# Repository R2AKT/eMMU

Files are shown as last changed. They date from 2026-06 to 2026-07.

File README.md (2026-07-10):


License addendum - https://github.com/R2AKT/eMMU/blob/main/Addendum.txt

# eMMU — Hardware Memory Management Unit for KR580VM80A / Intel 8080

Choose language / Выберите язык:
* [English](#-english)
* [Русский (Russian)](#-русский)

---

# 🇺🇸 English

# eMMU — Hardware Memory Management Unit for Intel 8080 (KR580VM80A)

## 📌 Project Overview
**eMMU (extended Memory Management Unit)** is a high-performance hardware memory management subsystem implemented entirely on discrete TTL logic (74LS, 74ALS series). The project is architected around the vintage **Intel 8080 (KR580VM80A)** 8-bit microprocessor kit and radically overcomes its native architectural limitations.

### Key Features:
* **Memory Expansion:** Increases addressable physical RAM space from **64 KB to 4 MB**.
* **Privilege Isolation:** True hardware-enforced **RING 0 (Kernel Mode)** and **RING 3 (User Mode)** execution environments.
* **Hardware Exceptions:** Immediate generation of a dedicated `/PRIVILEGE_VIOLATION` interrupt upon unauthorized I/O access.
* **Instruction Filtering:** In-flight opcode interception that silently substitutes forbidden user-space interrupt commands (`DI`/`EI`) with safe `NOP` (`0x00`) instructions.
* **Isolated Data Override:** Secure cross-privilege memory window with absolute hardware Write-Protection (WP) blocking of kernel-space RAM during data transfers.
* **Reactive I/O Firewall:** Instant hardware Z-state disabling of the KR580VK38 system controller and premature `~{CS}` peripheral dropping to block rogue I/O cycles.

---

## 🗺️ System Memory Architecture (Memory Map)
The processor's 64 KB logical address space is divided into **4 fixed segments of 16 KB each**. Translation is performed by dynamically swapping logical lines `/AB14` and `/AB15` with physical high-order address lines `/MAB14`...`/MAB21` via **74LS257 (K555KP11)** multiplexers (`DD4`, `DD15`) backed by **74LS670 (K555IR26)** 4x4 register file window memory arrays (`DD7`, `DD16`).

### Logical Segment Map (64 KB) in User Mode (RING 3):
* **`0x0000 – 0x3FFF` [Segment 0]**: **Fully Free User RAM**. Dedicated entirely to user-space application code, stack, or variables. No kernel interrupt vectors or system syscall vectors are reserved here.
* **`0x4000 – 0x7FFF` [Segment 1]**: **Fully Free User RAM**. Available for application execution or heap space.
* **`0x8000 – 0xBFFF` [Segment 2]**: **Fully Free User RAM**. Architecturally designated as the controlled override window for secure Kernel-to-User data exchanges.
* **`0xC000 – 0xFFFF` [Segment 3]**: **Fully Free User RAM**. Allocated for the user-space isolated execution stack and process variables.

### Lower Virtual Space Isolation and Context Switching:
User applications maintain absolute, uninhibited control over the entire 64 KB space—including the lower virtual range (`0x0000–0x0037`)—as the processor never reads instructions from this user-space context during interrupt traps.

The moment a hardware interrupt occurs (`~{INTA} = 0`) or a software trap is triggered, the eMMU forcefully overrides the bus, **switching the memory mapping to the Kernel context (RING 0)**. The true system interrupt vector table is activated on the physical bus exclusively in Kernel mode and strictly starting from address `0x0038` onwards via the `VD1–VD3` diode selector array (`~{LOW_8K} = 0`) and the `DD17` trigger clocked by the `/M1_TRUE` signal.

## 🔌 I/O Control Port Map
MMU configuration and page-table management are handled via a privileged, hardware-isolated I/O port range: **`0x70` – `0x77`** (decoded by **`DD14` / K555ID7 / 74LS138**). Access to these ports is strictly gated by the **`DD12` (K555SP1 / 74LS85)** digital comparator and jumpers `JP1–JP4`. Any unauthorized access attempt from RING 3 instantly locks the decoder and aborts the system cycle.

| Privileged I/O Port | Signal Name | Bus Direction | Functional Description inside the MMU |
| :---: | :--- | :---: | :--- |
| **`0x70`** | `~{PORT_70_SEL}` | Write Only | Writes the physical page index for **Segment 0** into K555IR26 |
| **`0x71`** | `~{PORT_71_SEL}` | Write Only | Writes the physical page index for **Segment 1** into K555IR26 |
| **`0x72`** | `~{PORT_72_SEL}` | Write Only | Writes the physical page index for **Segment 2** into K555IR26 |
| **`0x73`** | `~{PORT_73_SEL}` | Write Only | Writes the physical page index for **Segment 3** into K555IR26 |
| **`0x74`** | `~{PORT_74_SEL}` | — | Reserved internal auxiliary control line |
| **`0x75`** | `~{PORT_75_SEL}` | Write Only | **Shadow ROM Override:** Flips trigger `DD3` to permanently disable Boot ROM after BIOS is cached to Kernel RAM |
| **`0x76`** | `~{PORT_76_SEL}` | Write Only | **KERNEL_OVERRIDE Control:** Toggles trigger `DD19` to engage/disengage user-space window mapping |
| **`0x77`** | `~{PORT_77_SEL}` | — | Reserved system port for future hardware extensions |

---

## 🛠️ Hardware-Enforced Protection Mechanisms

### 1. Boot Logic, Shadow ROM, and Diode Selection (`VD1–VD3`)
At power-on or system reset (`~{RESOUT} = 0`), the `DD3` trigger defaults to `~{ROM_EN} = 0`, forcing raw physical memory translation off. The **`VD1–VD3`** diode array strictly monitors logical address ranges, asserting **`~{LOW_8K} = 0`**. 

Gated together with `~{ROM_CS}`, this activates the `DD35` Shadow Boot ROM **strictly within the logical bounds of `0x0000–0x1FFF`**, completely preventing phantom mirroring across higher address blocks. The primary bootloader copies the core BIOS/OS image into fast physical system RAM, then fires an `OUT 0x75` command. The resulting `~{PORT_75_SEL}` strobe flips the `DD3` trigger—permanently disabling the Shadow ROM and the diode array until the next cold reset, instantly reclaiming Segment 0 for user space.

### 2. Privileged I/O Gating and the Reactive I/O Firewall
The board incorporates a reactive hardware monitoring matrix over the I/O subsystem. In RING 3, discrete gates `DD11` and `DD44` actively watch the execution of system input/output command strobes **`~{IOR}`** and **`~{IOW}`**.
* **Violation Detection:** Any rogue `IN`/`OUT` execution from user space targeted at protected peripheral spaces triggers an immediate **`~{IO_VIOLATION} = 0`** fault signal. Trigger **`DD55`** latches this hardware exception and relays a persistent **`/PRIVILEGE_VIOLATION`** interrupt request to the system controller via the `JP5–JP12` matrix. The kernel clears the exception state by pulsing port `0x76`.
* **Hardware Interception Matrix:** Simultaneously with the interrupt, the asserted `~{IO_VIOLATION} = 0` line instantly forces the main **KR580VK38** system controller data bus transceivers into a high-impedance Z-state, effectively disconnecting the CPU's local lines. Mitigation is achieved by **prematurely forcing Chip Select (`~{CS}`) lines to high (`1`)** on the external peripheral decoders. This hardware drop completely isolates external LSI chips (such as KR580VV55 or KR580VI53) *before* the active logical `~{IOW}` or `~{IOR}` bus signals finish their machine cycle, making the theft or corruption of internal peripheral control data physically impossible.

### 3. Opcode Invalidation (`DI` / `EI` Gating)
During RING 3 execution, the `DD26` decoder tracks the exact appearance of `0xF3` (`DI`) and `0xFB` (`EI`) opcodes strictly inside `M1` fetch cycles. Upon matches, the `~{DI-EI_CODE}` line falls low, opening the `DD13` bus-override buffer which grounds the processor's data lines on-the-fly. The processor registers a safe **`NOP` (`0x00`)** instruction instead, leaving user-space interrupts enabled and maintaining total OS multitasking stability.

### 4. Delayed Privilege Escalation and Symmetric Returns
When an interrupt hits (`~{INTA} = 0`), the CPU executes the initial branch cycle completely in RING 3. The return address (`PC`) is written to the user stack using user-space translation tables. Because privilege escalation to RING 0 (`/KERNEL_MODE = 1`) is strictly delayed until the first opcode fetch (`M1`) from vector `0x0038` (handled by the `/M1_TRUE` trigger), the kernel's physical pages are fundamentally insulated from being overwritten by a corrupt user-space `SP`.

Symmetric returns are cleanly automated via the `~{RET_STROBE}` line, which intercepts the `RET` (`0xC9`) instruction in its `M1` cycle. The processor reads its return coordinates from the stack *after* the hardware has already swapped the context back to RING 3, ensuring the kernel's execution context is kept clean.

### 5. Secure Context Override (`KERNEL_OVERRIDE`)
To transfer blocks between Kernel Mode and User Mode safely, the kernel writes to port `0x76`, setting `~{KERNEL_OVERRIDE} = 0`. Inside Segment 2 (`0x8000–0xBFFF`), a **K555LI1 (74LS08)** logical `AND` gate forces the IR26 registers and KP11 multiplexers into translation mode. While Segments 0, 1, and 3 continue to map true kernel pages (mirrored by the OS inside register positions 0, 1, and 3 of the IR26 files), Segment 2 securely routes data directly to the physical user process page.

Crucially, the active-low `~{KERNEL_OVERRIDE_EN} = 0` line is fed directly into the active-low enable input `E1` (pin 4) of the **`DD39`** kernel memory decoder. The moment an override cycle runs, **`DD39` is forcefully disabled by the hardware**, driving `~{CS_32}` and `~{CS_64}` high. Physical kernel RAM chips (`DD50`, `DD51`) are completely decoupled from the data bus, making malicious memory corruption through illegal user pointers mathematically impossible.

---

# 🇷🇺 Русский

## 📌 Описание проекта
**eMMU (extended Memory Management Unit)** — это высокоуровневый аппаратный диспетчер памяти, реализованный на жесткой ТТЛ-логике (серии К555/К1533). Проект спроектирован вокруг классического микропроцессорного комплекта **КР580ВМ80А (Intel 8080)** и полностью решает его базовые архитектурные ограничения.

### Ключевые возможности:
* **Расширение памяти:** Адресация физического ОЗУ увеличивается с **64 КБ до 4 МБ**.
* **Разделение привилегий:** Полноценная аппаратная реализация режимов **RING 0 (Ядро)** и **RING 3 (Пользователь)**.
* **Аппаратные исключения:** Генерация прерывания `/PRIVILEGE_VIOLATION` при несанкционированном доступе к портам ввода-вывода.
* **Фильтрация команд:** Перехват и «тихая» подмена запрещенных инструкций `DI`/`EI` в пространстве пользователя на безопасные `NOP` (`0x00`).
* **Защищенный оверрайд:** Межпривилегированный сегмент обмена данными с жесткой WP-блокировкой системного ОЗУ.
* **Аппаратный I/O Firewall:** Принудительное Z-глушение ВК38 и опережающее отключение сигналов `~{CS}` периферии при нелегальном доступе к портам в RING 3.

---

## 🗺️ Архитектурная карта памяти (Memory Map)
Логическое адресное пространство процессора (64 КБ) разделено на **4 фиксированных сегмента объемом по 16 КБ каждое**. Трансляция осуществляется заменой логических линий `/AB14` и `/AB15` на физические `/MAB14`...`/MAB21` через мультиплексоторы **К555КП11 (`DD4`, `DD15`)** и регистровую память окон **К555ИР26 (`DD7`, `DD16`)**.

### Сетка логических сегментов процессора (64 КБ) в режиме Пользователя (RING 3):
* **`0x0000 – 0x3FFF` [Сегмент 0]**: **Полностью свободен**. Назначение определяется пользователем (код / стек / данные).
* **`0x4000 – 0x7FFF` [Сегмент 1]**: **Полностью свободен**. Назначение определяется пользователем (код / стек / данные).
* **`0x8000 – 0xBFFF` [Сегмент 2]**: **Полностью свободен**. Назначение определяется пользователем. Аппаратно выделен как область контролируемого оверрайда для доступа Ядра к пользовательской памяти.
* **`0xC000 – 0xFFFF` [Сегмент 3]**: **Полностью свободен**. Назначение определяется пользователем (код / стек / данные).

### Механизм изоляции и принудительного переключения:
Все четыре сегмента в пользовательском режиме полностью очищены от обязательного присутствия системных структур ядра. Пользовательское ПО может монопольно распоряжаться всем пространством 64 КБ.

В момент программного вызова (команды `RST`, `CALL`) или аппаратного прерывания (`~{INTA} = 0`), eMMU аппаратно перехватывает шину и **принудительно переключает адресное пространство в контекст Ядра (RING 0)**. Истинная системная база ОС активируется на физической шине строго в режиме ядра, защищая пользовательские данные.

---

## 🔌 Карта портов ввода-вывода (I/O Control Map)
Управление диспетчером памяти выполняется через диапазон портов **`0x70` – `0x77`** (дешифратор **`DD14` / К555ИД7**). Доступ аппаратно защищен компаратором **`DD12` (К555СП1)** и блоком джамперов `JP1–JP4`. Обращение из RING 3 мгновенно блокирует дешифратор и вызывает сбой системы.

| Порт I/O | Название сигнала | Направление | Функциональное назначение в MMU |
| :---: | :--- | :---: | :--- |
| **`0x70`** | `~{PORT_70_SEL}` | Запись | Физический адрес страницы для **Сегмента 0** в К555ИР26 |
| **`0x71`** | `~{PORT_71_SEL}` | Запись | Физический адрес страницы для **Сегмента 1** в К555ИР26 |
| **`0x72`** | `~{PORT_72_SEL}` | Запись | Физический адрес страницы для **Сегмента 2** в К555ИР26 |
| **`0x73`** | `~{PORT_73_SEL}` | Запись | Физический адрес страницы для **Сегмента 3** в К555ИР26 |
| **`0x74`** | `~{PORT_74_SEL}` | — | Резервный управляющий канал периферии |
| **`0x75`** | `~{PORT_75_SEL}` | Запись | **Отключение теневого ПЗУ**: защелка триггера `DD3` после копирования BIOS в ОЗУ ядра |
| **`0x76`** | `~{PORT_76_SEL}` | Запись | **Включение / выключение режима KERNEL_OVERRIDE** (управление триггером `DD19`) |
| **`0x77`** | `~{PORT_77_SEL}` | — | Резервный системный порт диспетчера |

---

## 🛠️ Механизмы аппаратной защиты

### 1. Логика старта, теневое ПЗУ и диодный селектор `VD1–VD3`
При подаче питания или системном сбросе (`~{RESOUT} = 0`) триггер `DD3` автоматически выставляет `~{ROM_EN} = 0`. Трансляция отключена. Диодная сборка **`VD1–VD3`** непрерывно идентифицирует обращения процессора к нижним адресам памяти и формирует сигнал **`~{LOW_8K} = 0`**. 

В связке с цепью `~{ROM_CS}` это аппаратно активирует теневое ПЗУ `DD35` **строго в границах диапазона `0x0000–0x1FFF`**, исключая его ложное зеркалирование на остальную память. Первичный бутлоадер переносит код BIOS/ОС в физическое системное ОЗУ, после чего выполняет команду `OUT 0x75`. Сигнал `~{PORT_75_SEL}` сбрасывает триггер `DD3` — теневое ПЗУ и диодная сборка навсегда отключаются до следующего аппаратного RESET, освобождая Сегмент 0 для полноценного использования пользователем.

### 2. Защита ввода-вывода и Экспериментальный I/O Firewall
Плата реализует жесткий аппаратный контроль пространства ввода-вывода. В режиме RING 3 элементы логики `DD11` и `DD44` непрерывно мониторят появление системных стробов чтения/записи портов **`~{IOR}`** и **`~{IOW}`**.
* **Детектирование нарушений:** Любая попытка вызова команд `IN`/`OUT` в пользовательском пространстве к служебным/управляющим портам eMMU формирует сигнал **`~{IO_VIOLATION} = 0`**. Триггер **`DD55`** мгновенно фиксирует (защелкивает) это событие и через систему джамперов `JP5–JP12` отправляет сигнал прерывания **`/PRIVILEGE_VIOLATION`** контроллеру прерываний для обработки операционной системой. Сброс триггера нарушения производится ядром через порт `0x76`.
* **ЭКСПЕРИМЕНТАЛЬНАЯ защита (Блокировка периферии):** Сигнал нарушения `~{IO_VIOLATION} = 0` мгновенно переводит системный контроллер **КР580ВК38** в высокоимпедансное Z-состояние, изолируя локальные линии данных процессора. Предотвращение несанкционированного выполнения операции (чтения служебных/управляющих данных или записи деструктивного мусора в регистры) достигается за счет **опережающего аппаратного снятия сигналов выбора кристалла `~{CS}`** с дешифраторов внешних периферийных модулей (они принудительно уводятся в `1`). Блокировка срабатывания логики внешних БИС происходит до того, как текущие системные стробы `~{IOW}` или `~{IOR}` успеют завершить машинный цикл и подняться обратно в пассивное состояние, гарантируя полную изоляцию служебных портов.

### 3. Блокировка `DI` / `EI`
В пользовательском режиме компаратор `DD26` отслеживает опкоды `0xF3` (`DI`) и `0xFB` (`EI`) в цикле `M1`. При совпадении активируется линия `~{DI-EI_CODE}`, открывая буфер глушения шины `DD13`, который прижимает данные процессора к нулю. Процессор выполняет операцию **`NOP` (`0x00`)**.

### 4. Межпривилегированные переходы и Стек
При прерывании или системном вызове (`~{INTA} = 0`) процессор выполняет переход полностью в контексте RING 3. Адрес возврата (`PC`) сохраняется в текущем пользовательском стеке по правилам трансляции страниц пользователя. Поскольку переключение в RING 0 (`/KERNEL_MODE = 1`) происходит отложено — строго по сигналу `/M1_TRUE` при выборке первой инструкции обработчика ядра из предела `0x0038`, физические адреса ядра гарантированно защищены от записи со стороны пользовательского указателя стека `SP`.

Автоматический выход в RING 3 осуществляется по сигналу `~{RET_STROBE}` при детекции опкода `RET` (`0xC9`) в цикле `M1`. Чтение стека процессором происходит уже в контексте пользовательских таблиц страниц.

### 5. Синхронизация KERNEL_OVERRIDE
Включение режима контролируемого доступа к памяти пользователя производится командой `OUT 0x76`, взводящей линию `~{KERNEL_OVERRIDE} = 0`. В режиме оверрайда, привязанном строго к Сегменту 2 (`0x8000–0xBFFF`), логическое «И» на микросхеме **К555ЛИ1** принудительно включает ИР26 и КП11. Для Сегментов 0, 1 и 3 на шину транслируются системные адреса ядра (продублированные ОС в ячейках 0, 1 и 3 ИР26), а для Сегмента 2 — страница пользователя.

Строб `~{KERNEL_OVERRIDE_EN} = 0` заведен на инверсный вход разрешения `E1` дешифратора памяти ядра **`DD39`**. В момент работы оверрайда дешифратор `DD39` **аппаратно блокируется**, уводя сигналы `~{CS_32}` и `~{CS_64}` в пассивную единицу, что полностью исключает риск затирания памяти ядра пользовательскими данными. По окончании работы ядро сбрасывает режим оверрайда повторной записью в порт `0x76`.

---
*Engineered as part of the eMMU Protected System Architecture.*

---

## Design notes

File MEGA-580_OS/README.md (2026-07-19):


License addendum - https://github.com/R2AKT/eMMU/blob/main/Addendum.txt

# 🖥️ MEGA-580 OS

**Монолитная операционная система реального времени для архитектуры КР580ВМ80А (i8080-совместимая)**







---

## 📖 О проекте

**MEGA-580 OS** — экспериментальная монолитная операционная система, написанная полностью на ассемблере КР580ВМ80А (~3500 строк кода). ОС разработана для работы на советской микроэлектронике серии КР580 и поддерживает современные POSIX-подобные концепции: вытесняющую многозадачность, виртуальную файловую систему, символьные устройства, сигналы и аппаратную защиту памяти.

Ключевая архитектурная особенность — использование собственной сегментно-страничной системы памяти **eMMU rev_2.0** с четырьмя сегментами по 16 КБ и режимом `KERNEL_OVERRIDE` для безопасного доступа ядра (Ring 0) к пользовательской памяти (Ring 3).

---

## ⚠️ Важное примечание о статусе проекта

> **Подсистема системных вызовов (`SYSCALL_TABLE`) находится в стадии активной переработки.**  
> В текущей сборке таблица `SYSCALL_TABLE` содержит только заглушку `syscall_bad_number`. Реализация полного набора POSIX-сисколлов (`sys_exit`, `sys_open`, `sys_read`, `sys_write`, `sys_gettimeofday` и др.) запланирована в ближайших коммитах.
>
> **Вся остальная инфраструктура ядра** (VFS, RTC, NVRAM, TTY, LPT, планировщик, обработчик прерываний) **полностью функциональна, протестирована и готова к интеграции**.

---

## ✨ Ключевые особенности

### 🏗️ Архитектура ядра
- **Монолитное ядро** с вытесняющей многозадачностью
- **Двухуровневая защита памяти** (Ring 0 / Ring 3) через eMMU rev_2.0
- **Режим KERNEL_OVERRIDE** для атомарного доступа ядра к памяти Ring 3
- **Динамические приоритеты** с aging и насыщением до 255
- **POSIX-подобные сигналы** (16 сигналов, маски SIG_FATAL)
- **SMC-патчинг** (Self-Modifying Code) для адресации портов ISR

### 📁 Виртуальная файловая система (VFS)
- **Таблица коммутации драйверов** `VFS_SWITCH_TABLE` (32 Major × 10 байт)
- **Таблица монтирования устройств** `DEV_MOUNT_TABLE` (16 слотов × 6 байт)
- **Таблица Inode** `VFS_INODE_TABLE` (64 Inode × 16 байт)
- **Глобальная таблица файлов** `SYS_FILE_TABLE` (128 дескрипторов × 10 байт)
- **Локальная таблица FD** в PCB (16 дескрипторов на процесс)
- **Оптимизация хвостового вызова** через трюк `XTHL` в `k_vfs_dispatch`

### 🕐 Подсистема RTC/NVRAM
- **Аппаратные часы реального времени** на базе КР512ВИ1 (аналог DS12885)
- **Двусторонний конвертер эпохи**: `k_rtc_convert_raw_to_unix` ↔ `k_rtc_convert_unix_to_raw`
- **32-битный UNIX Time** (Little-Endian) с диапазоном 01.01.2026 — 07.02.2106
- **Защита от бита UIP**: атомарное чтение в окно 244 мкс
- **NVRAM 50 байт** (адреса 0x0E — 0x3F) с блочными операциями
- **Обработка високосных лет** через таблицу `k_rtc_days_before_month`

### 🖥️ Подсистема TTY
- **До 4-х независимых консолей** (TTY0 — TTY3)
- **Приоритетный автодетект**: КР580ВВ51А + КР580ВИ53, затем NS16550
- **Кольцевые буферы** RX/TX по 64 байта
- **POSIX termios-флаги**: ECHO, ICANON, ISIG, ICRNL, OPOST
- **Управляющие символы**: Ctrl+C, Ctrl+D, Ctrl+U, Backspace, Ctrl+Q/S

### 🖨️ Подсистема LPT
- **До 2-х параллельных портов** (LPT0, LPT1)
- **Приоритетный автодетект**: Intel 82C11, затем КР580ВВ55А
- **FIFO-буфер отложенной записи** 48 байт
- **Асинхронный Handshake Centronics** через BSR-команды РРУ
- **32-битный счётчик** выведенных байт `O_LP_BYTES_WRITTEN`

---

## 🖥️ Поддерживаемое оборудование

### Микропроцессоры
- **КР580ВМ80А** (i8080-совместимый, 2.5 МГц)

### Контроллеры прерываний
- **КР580ВН59** (аналог Intel 8259A) — Master

### Системные таймеры
- **КР580ВИ53** (аналог Intel 8253) — квант 20 мс (50 Гц)

### Часы реального времени
- **КР512ВИ1** (аналог DS12885) — RTC + 50 байт NVRAM

### Последовательные интерфейсы
- **КР580ВВ51А** (аналог Intel 8251A) — USART
- **NS16550 / 16550A** — UART с FIFO

### Параллельные интерфейсы
- **КР580ВВ55А** (аналог Intel 8255A) — PPI
- **Intel 82C11** — специализированный LPT-контроллер

### Контроллеры памяти
- **К555ИР26** — сегментно-страничный модуль eMMU rev_2.0

---

## 📂 Структура проекта

```
MEGA-580_OS/
├── kernel.lst                    # Монолитный листинг ядра (основной файл)
├── kernel.mem                    # Распределение памяти Ring 0
│
├── include/                      # Заголовочные файлы
│   ├── kernel.inc                # Основные константы ядра
│   ├── kernel_time.inc           # Константы таймера
│   ├── kernel_time.mem           # SYS_TICK_COUNTER, SYS_UNIX_TIME
│   ├── hw.inc                    # Порты периферии
│   ├── pcb.inc / pcb.mem         # Структура PCB (64 байта)
│   ├── vfs.inc / vfs.mem         # VFS-константы и таблицы
│   ├── chrdev.inc / chrdev.mem   # Символьные устройства
│   ├── syscall.inc / syscall.mem # Таблица сисколлов
│   ├── tty.inc / tty.mem         # TTY-структуры (160 байт)
│   ├── lp.inc / lp.mem           # LPT-структуры (80 байт)
│   ├── signals.inc               # POSIX-сигналы (16 бит)
│   ├── devices.inc               # Major/Minor номера
│   ├── hw_i8251.inc / mem        # КР580ВВ51А
│   ├── hw_ns16550.inc / mem      # NS16550
│   ├── hw_rtc.inc / mem          # КР512ВИ1
│   ├── rtc.inc / rtc.mem         # RTC подсистема
│   ├── rtc_core.inc              # RTC VFS-мосты
│   ├── rtc_epoch.inc / mem       # Epoch-конвертер
│   ├── rtc_nvram.inc / mem       # NVRAM операции
│   └── panic.inc                 # Коды паники ядра
│
└── kernel/                       # Модули ядра
    ├── vfs.asm                   # VFS-диспетчеры
    ├── pcb.asm                   # Планировщик
    ├── syscall.asm               # Шлюз сисколлов
    ├── chrdev.asm                # Коммутатор символьных устройств
    ├── tty_core.asm              # TTY-драйвер
    ├── lp_core.asm               # LPT-драйвер
    ├── hw.asm                    # Инициализация периферии
    ├── hw_i8251.asm              # HAL КР580ВВ51А
    ├── hw_ns16550.asm            # HAL NS16550
    ├── hw_lp8255.asm             # HAL КР580ВВ55А
    ├── hw_lp82c11.asm            # HAL Intel 82C11
    ├── hw_rtc.asm                # HAL КР512ВИ1
    ├── rtc.asm                   # RTC-драйвер
    ├── rtc_core.asm              # VFS-мосты RTC/NVRAM
    ├── rtc_epoch.asm             # Epoch-конвертер
    ├── rtc_nvram.asm             # NVRAM-операции
    ├── panic.asm                 # Обработчик паники
    └── sys_write.asm             # Сисколл записи
```

---

## 📊 Технические метрики

| Параметр | Значение |
|---|---|
| Объём кода | ~3500 строк ассемблера |
| Размер ядра | 8 КБ (тень ПЗУ) |
| Максимум процессов | 32 (`PCB_TABLE` = 2 КБ) |
| Размер PCB | 64 байта |
| Квант планировщика | 20 мс (50 Гц) |
| Максимум TTY | 4 консоли |
| Максимум LPT | 2 порта |
| Размер TTY-слота | 160 байт |
| Размер LPT-слота | 80 байт |
| Размер файла VFS | 10 байт |
| Максимум файлов в системе | 128 |
| Максимум файлов на процесс | 16 |
| Объём NVRAM | 50 байт |
| Размер сегмента eMMU | 16 КБ |
| Количество сегментов | 4 |
| Поддержка високосных лет | ✅ (до 2099) |
| Диапазон UNIX_TIME | 01.01.2026 — 07.02.2106 |

---

## 🚀 Последовательность холодного старта

```
┌─────────────────────────────────────────────────────────────┐
│ 1. Теневое ПЗУ (0x0000)                                     │
│    └─ boot_start → cold_boot                                │
├─────────────────────────────────────────────────────────────┤
│ 2. Перенос ядра в верхнее ОЗУ (EMMU_PAGE_2 = 0x8000)       │
│    └─ LXI H, upper_ram_stage2+EMMU_PAGE_2 → PCHL            │
├─────────────────────────────────────────────────────────────┤
│ 3. Отключение ПЗУ через порт 0x75                           │
│    └─ OUT EMMU_ROM_DISABLE                                  │
├─────────────────────────────────────────────────────────────┤
│ 4. Зеркальный перенос ядра в нижнее ОЗУ (0x0000)           │
│    └─ EMMU_PAGE_2 → EMMU_PAGE_0                             │
├─────────────────────────────────────────────────────────────┤
│ 5. Чистый старт из нижнего ОЗУ                              │
│    └─ kernel_clean_start                                    │
├─────────────────────────────────────────────────────────────┤
│ 6. Инициализация подсистем (Этапы 5.1 — 5.11)              │
│    ├─ 5.1  k_pcb_subsys_init                                │
│    ├─ 5.2  k_tty_subsys_init                                │
│    ├─ 5.3  k_lp_subsys_init                                 │
│    ├─ 5.4  k_vfs_subsys_init + регистрация драйверов       │
│    ├─ 5.5  hw_sys_init (ВИ53)                               │
│    ├─ 5.6  k_rtc_boot_sync_unix_time                        │
│    ├─ 5.7  k_tty_carousel_auto_build                        │
│    ├─ 5.8  vfs_mount_tty_nodes                              │
│    ├─ 5.9  k_lp_carousel_auto_build                         │
│    ├─ 5.10 vfs_mount_lp_nodes                               │
│    └─ 5.11 hw_int_init (ВН59)                               │
├─────────────────────────────────────────────────────────────┤
│ 7. Разрешение прерываний                                    │
│    └─ EOI → EI → idle_loop (HLT)                            │
└─────────────────────────────────────────────────────────────┘
```

---

## 🏛️ Архитектура VFS

### Двухуровневая система диспетчеризации

```
Ring 3: write(fd, buf, len)
    │
    ▼
sys_call_entry (RST 6)
    │
    ▼
sys_write
    │
    ▼
k_vfs_get_file_struct_address(fd) → HL = адрес Inode
    │
    ▼
vfs_chrdev_write(Major, Minor, buf, len)
    │
    ▼
SYS_CHRDEV_SWITCH[Major].write_ptr → PCHL
    │
    ▼
tty_write_bridge / lp_write_bridge / rtc_write_bridge
    │
    ▼
Физический драйвер (hw_i8251_put_char / hw_82c11_put_char)
    │
    ▼
Кремний (КР580ВВ51А / Intel 82C11 / КР512ВИ1)
```

### Major-номера устройств

| Major | Устройство | Описание |
|---|---|---|
| 1 | `/dev/null` | Системный поглотитель данных |
| 2 | `/dev/zero` | Системный генератор нулей |
| 3 | `/dev/mem` | Прямой физический доступ к ОЗУ ядра |
| 4 | `/dev/tty*` | Последовательные консоли (ВВ51/16550) |
| 5 | `/dev/pty*` | Псевдо-терминалы для сетевых сессий |
| 6 | `/dev/lp*` | Параллельный порт принтера (82C11/ВВ55А) |
| 8 | `/dev/rtc` | Аппаратные часы реального времени |
| 9 | `/dev/nvram` | Энергонезависимая память 50 байт |

---

## 🕐 Подсистема RTC/NVRAM

### Полный двусторонний стек конвертации

```
k_rtc_raw_sec..year  ←→  k_rtc_convert_raw_to_unix  ←→  SYS_UNIX_TIME (32 bit)
                            k_rtc_convert_unix_to_raw
```

### Ключевые особенности

- **Защита от бита UIP**: Чтение регистров только в безопасное окно 244 мкс
- **Тест через Регистр B**: Исключение ложных срабатываний от динамического бита UIP
- **Оптимизированная арифметика**: Умножение дней на 86400 через разложение `65536 + 20864`
- **Таблица `k_rtc_days_before_month`** в формате `.dw` (16 бит) для поддержки октября/ноября/декабря
- **Корректная обработка високосных лет**: `(год % 4 == 0) && (месяц > 2)`

### VFS-мосты

| Устройство | Major | Minor | Функции |
|---|---|---|---|
| `/dev/rtc` | 8 | 1 | `rtc_read_bridge`, `rtc_write_bridge` |
| `/dev/nvram` | 9 | 0 | `nvram_read_bridge`, `nvram_write_bridge` |

Все мосты используют атомарное управление `KERNEL_OVERRIDE` через порт `0x76` для безопасного доступа к памяти Ring 3.

---

## 🔄 Планировщик задач

### Динамические приоритеты с aging

```
Формула приоритета: DYNAMIC = STATIC + NICE + CPU_TICKS
Насыщение: min(255, DYNAMIC)
```

- **Штрафной счётчик**: `O_CPU_TICKS` увеличивается при каждом кванте выполнения
- **Aging**: `O_CPU_TICKS--` для всех процессов, кроме `ST_ZOMBIE`
- **Выбор кандидата**: Линейный скан 32 слотов `PCB_TABLE` с поиском минимума
- **Сброс тиков**: `O_CPU_TICKS = 0` для запускаемого процесса

### Обработка будильников (POSIX `alarm`)

Каждый квант (20 мс) ISR сканирует `O_ALARM_TICKS` всех процессов. При достижении нуля — доставка сигнала `SIGALRM` в старший байт маски `O_SIG_PENDING`.

---

## 📡 POSIX-сигналы

### 16-битная маска сигналов

**Младший байт** (`O_SIG_PENDING + 0`): сигналы 1 — 8
- `SIG_HUP` (1), `SIG_INT` (2), `SIG_QUIT` (3), `SIG_ILL` (4)
- `SIG_TRAP` (5), `SIG_ABRT` (6), `SIG_BUS` (7), `SIG_FPE` (8)

**Старший байт** (`O_SIG_PENDING + 1`): сигналы 9 — 16
- `SIG_KILL` (9), `SIG_USR1` (10), `SIG_SEGV` (11), `SIG_USR2` (12)
- `SIG_PIPE` (13), `SIG_ALRM` (14), `SIG_TERM` (15), `SIG_CHLD` (16)

### Комбинированные маски смертельных сигналов

```asm
SIG_FATAL_MASK_L = SIGHUP OR SIGINT OR SIGQUIT OR SIGILL OR SIGABRT OR SIGBUS OR SIGFPE
SIG_FATAL_MASK_H = SIGKILL OR SIGSEGV OR SIGTERM
```

---

## 🛡️ Безопасность и защита памяти

### eMMU rev_2.0

- **4 сегмента** по 16 КБ (`EMMU_PAGE_SIZE = 4000H`)
- **Ring 0 / Ring 3** разделение через порт `0x76` (`EMMU_OVERRIDE`)
- **Порты управления**: `0x70..0x73` (регистрация сегментов), `0x75` (отключение ПЗУ)

### Обработчик нарушения привилегий (`hw_privilege_violation_entry`)

При попытке Ring 3 выполнить `IN`/`OUT`/`EI`/`DI`:
1. Перевод процесса в статус `ST_ZOMBIE`
2. Освобождение физических страниц через `k_free_physical_page`
3. Закрытие всех открытых файлов
4. Переключение контекста на живой процесс через `switch_mmu_context`

---

## 🚧 Дорожная карта

### ✅ Реализовано
- [x] Холодный старт с переносом ядра в верхнее ОЗУ
- [x] Планировщик с динамическими приоритетами
- [x] VFS-диспетчер с оптимизацией `XTHL`
- [x] Автодетект TTY/LPT с SMC-патчингом
- [x] Полная подсистема RTC/NVRAM
- [x] Epoch-конвертер (двусторонний)
- [x] Обработчик паники с HEX-кодом
- [x] POSIX-сигналы (16 бит, маски `SIG_FATAL_*`)
- [x] Обработчик нарушения привилегий

### 🔄 В работе
- [ ] Полный набор системных вызовов (`sys_exit`, `sys_open`, `sys_read`, `sys_write`)
- [ ] Сисколл `sys_gettimeofday`
- [ ] Сисколл `sys_fork` / `sys_execve`
- [ ] Подсистема сигналов (`sys_sigaction`, `sys_kill`)

### 📋 Запланировано
- [ ] Блочная файловая система (RAM-диск, FDD)
- [ ] Сетевой стек (KSZ8851-16MML)
- [ ] IPC (пайпы, сокеты AF_UNIX)
- [ ] POSIX-будильник (`sys_alarm`)
- [ ] Динамические библиотеки (оверлеи)

---

## 🔧 Сборка

### Требования
- Ассемблер КР580ВМ80А (MACRO-80, ASxxxx или совместимый)
- Целевая платформа: КР580ВМ80А @ 2.5 МГц
- Минимум 4 МБ ОЗУ с eMMU rev_2.0

### Команда сборки
```bash
# Пример для ZASM
zasm -v2uwy kernel.asm
```

### Результат сборки
```
total time: 0.3137 sec.
no errors
```

---

## 📝 Лицензия

Проект разработан в образовательных и исследовательских целях.  
Архитектура ориентирована на советскую микроэлектронику серии КР580.

---

## 🤝 Вклад в проект

Приветствуются Pull Request'ы в следующих направлениях:
- Оптимизация ассемблерного кода
- Расширение POSIX-совместимости
- Тестирование на реальном железе
- Документация аппаратных интерфейсов
- Реализация недостающих системных вызовов

---

## 📚 Дополнительные ресурсы

- **КР580ВМ80А** — Микропроцессор. Техническое описание
- **КР580ВН59** — Контроллер прерываний. Спецификация
- **КР580ВИ53** — Программируемый таймер. Руководство
- **КР512ВИ1** — Часы реального времени. Даташит
- **КР580ВВ51А** — Универсальный синхронно-асинхронный приёмопередатчик
- **КР580ВВ55А** — Программируемый периферийный интерфейс

---

**Автор:** MEGA-580 OS Development Team  
**Версия:** 1.5.76 (сборка от 20.07.2026)  
**Статус:** Активная разработка

---

<div align="center">

**Сделано с ❤️ для советской микроэлектроники**

🖥️ КР580ВМ80А | 🕐 КР512ВИ1 | 📡 КР580ВВ51А | 🖨️ Intel 82C11

</div>

---
*Engineered as part of the eMMU Protected System Architecture.*
---

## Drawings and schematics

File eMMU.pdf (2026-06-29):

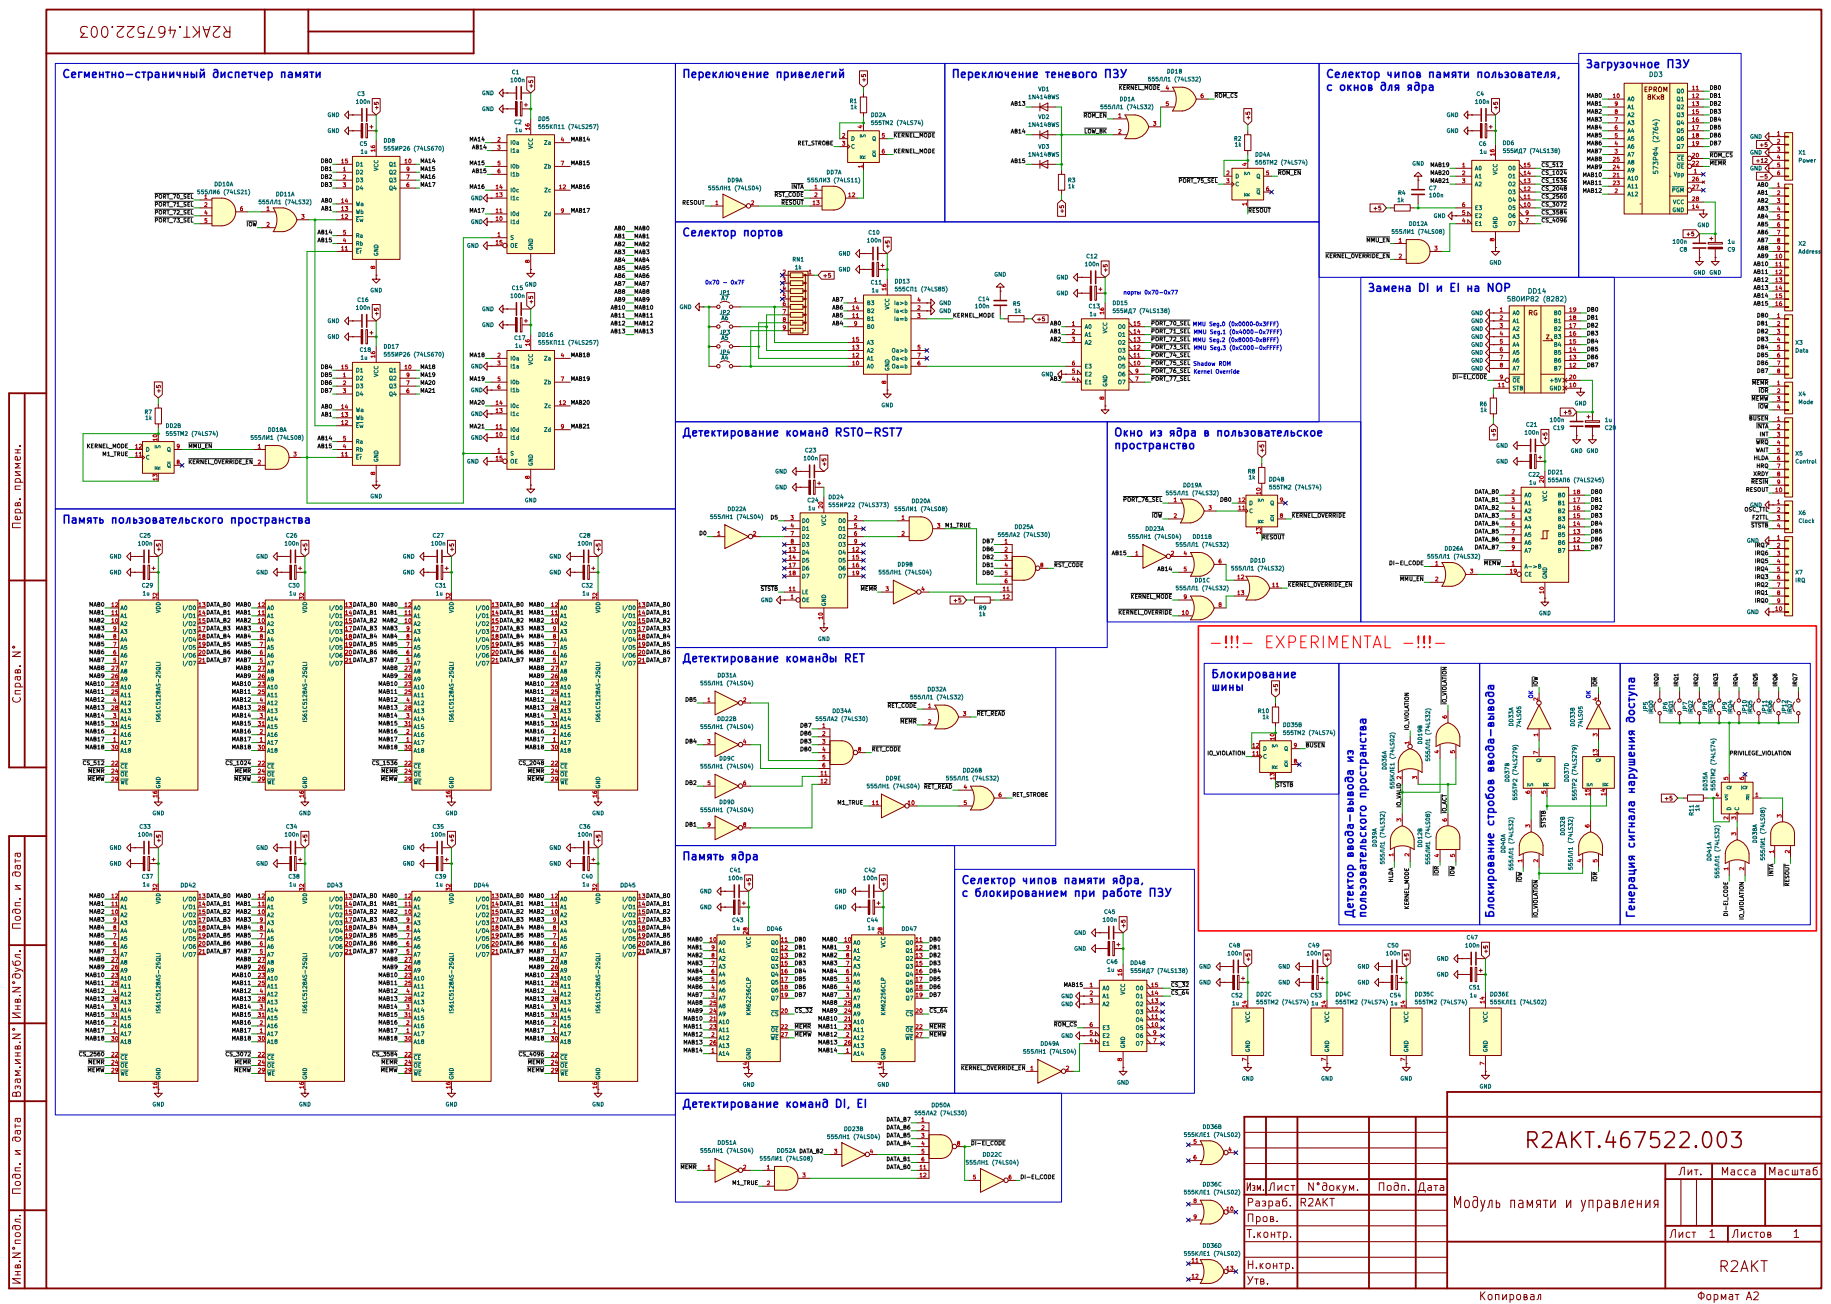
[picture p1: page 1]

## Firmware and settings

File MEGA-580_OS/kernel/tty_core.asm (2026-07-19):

;*
;[User Space (Ring 3)]
;└── write(fd, buf, len) / read(fd, buf, len)
;     │
;     ▼ (Аппаратное прерывание INT / RST 6)
;[Шлюз Системных Вызовов (Ring 0)]
;└── sys_call_entry (main.asm)
;     ├── sys_write (sys_io.asm) ──► vfs_chrdev_write (chrdev.asm) ──┐
;     └── sys_read  (sys_io.asm) ──► vfs_chrdev_read  (chrdev.asm) ──┤
;                                                                    │
;    ┌───────────────────────────────────────────────────────────────┘
;    ▼ (Динамическая индексация по таблице SYS_CHRDEV_SWITCH [MAJOR_TTY = 4])
;[Коммутационный слой VFS -> HAL Мосты]
;     ├── tty_write_bridge (tty.asm) [inline расчет: Minor * 160]
;     │    └── Физический косвенный вызов через PCHL драйвера (из хвоста слота TTY)
;     │         ├── hw_i8251_put_char (hw_i8251.asm) ──► [ Кремний КР580ВВ51А ]
;     │         └── hw_ns16550_put_char (hw_ns16550.asm) ──► [ Кремний NS16550 ]
;     │
;     └── tty_read_bridge (tty.asm) [inline расчет: Minor * 160]
;          └── Атомарное извлечение байта (под DI/EI) из ОЗУ Ring 0
;               └── TTY_TABLE[Minor].O_TTY_RX_BUFFER
;*
; =============================================================================
; /kernel/tty_core.asm - ИСПОЛНЯЕМЫЙ КОД ПОДСИС ТЕМЫ ТЕРМИНАЛЬНОГО ДВИЖКА ЯДРА
; =============================================================================
; =============================================================================
; НАЗВАНИЕ: tty_core.asm (Инициализация структур ОЗУ массива TTY)
; =============================================================================
k_tty_subsys_init:
    ; Вход:  Cold Boot, Ring 0, прерывания гарантированно заперты (DI).
    ; Задача: Полностью очистить и инициализировать все 4 независимых TTY-слота
    ;         внутри TTY_TABLE каноническими стартовыми значениями.
    
    LXI  H, TTY_TABLE               ; HL = Базовый физический адрес старта массива TTY
    MVI  B, MAX_TTY_DEVS            ; B = Счетчик внешнего цикла (4 консоли)

_tty_quad_alignment_loop:
    PUSH H                          ; Сохранили базовый адрес начала текущего 160-байтового слота

    ; --- ЭТАП 1: Полное предварительное зануление всего 160-байтового слота TTY ---
    MVI  C, TTY_STRUCT_SIZE         ; C = 160 байт
_tty_clear_row_loop:
    MVI  M, 00H
    INX  H
    DCR  C
    JNZ  _tty_clear_row_loop

    ; --- ЭТАП 2: Точечная инициализация POSIX атрибутов слота ---
    POP  H                          ; HL = Восстановили базовый адрес текущего TTY слота
    PUSH H                          ; Отложили на стек для перехода к следующей строке

    ; Прописываем O_TTY_C_IFLAG (+134) из дефолтных констант tty.inc
    LXI  D, O_TTY_C_IFLAG
    DAD  D                          ; HL -> Поле O_TTY_C_IFLAG (+134)
    MVI  M, DEF_C_IFLAG
    
    ; Прописываем O_TTY_C_OFLAG (+135) из дефолтных констант tty.inc
    INX  H                          ; HL -> Поле O_TTY_C_OFLAG (+135)
    MVI  M, DEF_C_OFLAG
    
    ; Прописываем O_TTY_C_LFLAG (+136) из дефолтных констант tty.inc
    INX  H                          ; HL -> Поле O_TTY_C_LFLAG (+136)
    MVI  M, DEF_C_LFLAG

    ; Инициализируем 8 байт массива управляющих символов O_TTY_C_CC (+137..+144)
    INX  H                          ; HL -> O_TTY_C_CC[VEOF] (+137)
    MVI  M, DEF_VEOF                ; Ctrl+D
    INX  H
    MVI  M, DEF_VEOL                ; \n
    INX  H
    MVI  M, DEF_VERASE              ; Backspace
    INX  H
    MVI  M, DEF_VKILL               ; Ctrl+U
    INX  H
    MVI  M, DEF_VINTR               ; Ctrl+C
    INX  H
    MVI  M, DEF_VQUIT               ; Ctrl+\
    INX  H
    MVI  M, DEF_VSTART              ; Ctrl+Q
    INX  H
    MVI  M, DEF_VSTOP               ; Ctrl+S

    ; Извлекаем чистую базу слота, чтобы исключить накопление ошибок INX H
    POP  H
    PUSH H
    LXI  D, O_TTY_WAIT_PID
    DAD  D                          ; HL -> Указывает точно на поле O_TTY_WAIT_PID (+145)
    MVI  M, UNBOUND_WAIT_PID        ; Зафиксировали 0xFF
    
    ; Явная инициализация группы переднего плана по строгому смещению структуры
    POP  H
    PUSH H
    LXI  D, O_TTY_PGRP
    DAD  D                          ; HL -> Указывает точно на поле O_TTY_PGRP (+147)
    MVI  M, UNBOUND_WAIT_PID        ; Зафиксировали 0xFF (Группа переднего плана отвязана)

    ; --- ЭТАП 3: Шаг к следующему TTY слоту таблицы ---
    POP  H                          ; HL = Базовый адрес текущего TTY слота
    LXI  D, TTY_STRUCT_SIZE         ; Сдвиг равен ровно 160 байтам (00A0h)
    DAD  D                          ; HL указывает строго на старт следующей TTY структуры
    
    DCR  B                          ; Уменьшаем счётчик сконфигурированных консолей
    JNZ  _tty_quad_alignment_loop   ; Повторяем цикл, пока не настроим все 4 терминала
    
    RET                             ; Возврат в k_power_on_init

; =============================================================================
; НАЗВАНИЕ: tty.asm (Диспетчер последовательной сборки активных TTY-слотов)
; =============================================================================
; =============================================================================
; НАЗВАНИЕ: tty.asm (Инстанцирующий диспетчер последовательной сборки карусели)
; ТОКЕН:    TOKEN::MEGA-580_OS_v1.5.81_K_TTY_CAROUSEL_INSTANCED_BUILD_20260709
; =============================================================================

; =============================================================================
; ПРОЦЕДУРА: k_tty_carousel_auto_build
; Вход:  Cold Boot, Ring 0, прерывания гарантированно заперты (DI).
; Задача: Перебрать все 4 физических порта, протестировать наличие железа
;         с приоритетом КР580ВВ51А, и связать их с ОЗУ-структурами ПОСЛЕДОВАТЕЛЬНО
;         методом SMC-инстанцирования базы в тела обработчиков прерываний.
; Выход: Все РОН полностью сохранены. Прерывания заперты.
; =============================================================================
k_tty_carousel_auto_build:
    PUSH B
    PUSH D
    PUSH H                          ; Спасли контекст супервизора Ring 0

    ; Инициализируем динамический указатель целевого логического TTY-слота
    LXI  D, TTY_TABLE               ; DE = Текущий свободный слот ОЗУ (на старте TTY0)

    ; --- ТЕСТИРОВАНИЕ АДРЕСА ПОРТА 0xA0 ---
    MVI  A, 0A0H
    CALL _tty_probe_hardware_gate
    
    ; --- ТЕСТИРОВАНИЕ АДРЕСА ПОРТА 0xB0 ---
    MVI  A, 0B0H
    CALL _tty_probe_hardware_gate
    
    ; --- ТЕСТИРОВАНИЕ АДРЕСА ПОРТА 0xC0 ---
    MVI  A, 0C0H
    CALL _tty_probe_hardware_gate
    
    ; --- ТЕСТИРОВАНИЕ АДРЕСА ПОРТА 0xD0 ---
    MVI  A, 0D0H
    CALL _tty_probe_hardware_gate

    POP  H
    POP  D
    POP  B                          ; Полное восстановление РОН супервизора
    RET
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

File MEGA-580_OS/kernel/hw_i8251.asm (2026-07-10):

;HAL-функции для КР580ВВ51А: hw_i8251_poll_status, hw_i8251_put_char, hw_i8251_get_char
; -----------------------------------------------------------------------------
; Инициализация USART КР580ВВ51А (9600,8N1, фактор K=16)
; -----------------------------------------------------------------------------
; =============================================================================
; ПРОЦЕДУРА: hw_i8251_init (ПОЛНАЯ ВЕРСИЯ С ДВУХЧИПОВЫМ АВТОДЕТЕКТОМ ВВ51+ВИ53)
; Вход:  DE = Физический адрес обрабатываемого TTY-слота (TTY0..TTY3).
; Выход: CY = 0 — Успех, ОБА чипа (ВВ51 и ВИ53) найдены и инициализированы.
;        CY = 1 — Отсутствует ВВ51 или отсутствует/неисправен ВИ53.
; =============================================================================
hw_i8251_init:
    PUSH B
    PUSH D
    PUSH H                          ; Сохранили контекст супервизора Ring 0

    ; --- ЭТАП 0: ДИНАМИЧЕСКОЕ ИЗВЛЕЧЕНИЕ ПАРАМЕТРОВ ИЗ СЛOТА ---
    MOV  H, D
    MOV  L, E                       ; HL = База TTY-слота
    
    PUSH H
    LXI  B, O_TTY_HW_BASE_PORT
    DAD  B                          ; HL -> O_TTY_HW_BASE_PORT (+155)
    MOV  C, M                       ; C = BASE_PORT данных чипа
    
    INX  H                          ; HL -> O_TTY_HW_DIV_LOW (+156)
    MOV  B, M                       ; B = DIV_LOW
    
    INX  H                          ; HL -> O_TTY_HW_DIV_HIGH (+157)
    MOV  A, M                       ; A = DIV_HIGH
    MOV  E, A                       ; E = DIV_HIGH
    POP  H                          ; HL = База TTY-слота

    ; --- ЭТАП 1: ВЫЧИСЛЕНИЕ АДРЕСОВ ПОРТОВ И SMC-ПАТЧИНГ ---
    ; 1.1: Командный порт ВВ51А (BASE_PORT + 1)
    MOV  A, C \ INR  A
    STA  _smc_prb_51_cmd + 1
	STA  _smc_prb_51_rst1 + 1
	STA  _smc_prb_51_rst2 + 1
    STA  _smc_prb_51_rst3 + 1
	STA  _smc_prb_51_int_rst + 1
	STA  _smc_prb_51_mode + 1
    STA  _smc_prb_51_start + 1

    ; 1.2: Управляющий порт КР580ВИ53 (BASE_PORT + 5)
    MOV  A, C
	ADI  5
    STA  _smc_prb_pit_cmd0 + 1
	STA  _smc_prb_pit_cmd1 + 1
    STA  _smc_prb_pit_test_cmd + 1
	STA  _smc_prb_pit_latch_cmd + 1

    ; 1.3: Порт Канала 0 ВИ53 (BASE_PORT + 2)
    MOV  A, C \ ADI  2
    STA  _smc_prb_pit_ch0_l + 1
	STA  _smc_prb_pit_ch0_h + 1
    STA  _smc_prb_pit_test_w_l + 1
	STA  _smc_prb_pit_test_w_h + 1
    STA  _smc_prb_pit_test_r_l + 1
	STA  _smc_prb_pit_test_r_h + 1

    ; 1.4: Порт Канала 1 ВИ53 (BASE_PORT + 3)
    MOV  A, C
	ADI  3
    STA  _smc_prb_pit_ch1_l + 1
	STA  _smc_prb_pit_ch1_h + 1

    ; === ЭТАП 1.1: АППАРАТНЫЙ АВТОДЕТЕКТ КР580ВВ51А ===
_smc_prb_51_cmd:
    IN   000H                       ; Читаем статус ВВ51
    CPI  0FFH
    JZ   _i8251_probe_fail_exit     ; Линия пуста — ВВ51 нет!

    ; === ЭТАП 1.2: АППАРАТНЫЙ АВТОДЕТЕКТ КР580ВИ53 (NEW!) ===
    ; Программируем Канал 0: Старший/Младший байт, Режим 0, Двоичный счет (0x30)
    MVI  A, 030H
_smc_prb_pit_test_cmd:
    OUT  000H                       ; Отправили приказ в управляющий порт ВИ53
    
    ; Записываем тестовое число 0xAA55 в Канал 0
    MVI  A, 055H                    ; Младший байт
_smc_prb_pit_test_w_l:
    OUT  000H
    MVI  A, 0AAH                    ; Старший байт
_smc_prb_pit_test_w_h:
    OUT  000H

    ; Команда Latch Counter для Канала 0 (0x00)
    XRA  A
_smc_prb_pit_latch_cmd:
    OUT  000H                       ; Фиксируем рантайм-значение триггера счетчика

    ; Считываем обратно и верифицируем младший байт
_smc_prb_pit_test_r_l:
    IN   000H
    CPI  055H                       
    JNZ  _i8251_probe_fail_exit     ; Не совпало — ВИ53 отсутствует или неисправен!

    ; Считываем обратно и верифицируем старший байт
_smc_prb_pit_test_r_h:
    IN   000H
    CPI  0AAH
    JNZ  _i8251_probe_fail_exit     ; Не совпало — ВИ53 отсутствует!

    ; === ОБА ЧИПА НАЙДЕНЫ И ОПРАШЕНЫ УСПЕШНО — ЗАПУСКАЕМ РАБОЧИЙ РЕЖИМ ===
    ; Инициализация ВВ51А
    XRA  A
_smc_prb_51_rst1:
    OUT  000H
_smc_prb_51_rst2:
	OUT 000H
_smc_prb_51_rst3:
	OUT 000H
    MVI  A, I8251_CMD_RESET
_smc_prb_51_int_rst:
	OUT 000H
	NOP
    MVI  A, I8251_MODE_8N1_X16
_smc_prb_51_mode:
	OUT 000H
	NOP
    MVI  A, I8251_CMD_START
_smc_prb_51_start:
	OUT 000H

    ; Рабочая перепрошивка ВИ53 на заданную в структуре скорость (Режим 3)
    MVI  A, PIT_CW_CH0_M3
_smc_prb_pit_cmd0:
	OUT 000H
    MOV  A, B
_smc_prb_pit_ch0_l:
	OUT 000H
    MOV  A, E
_smc_prb_pit_ch0_h:
	OUT 000H

    MVI  A, PIT_CW_CH1_M3
_smc_prb_pit_cmd1:
	OUT 000H
    MOV  A, B
_smc_prb_pit_ch1_l:
	OUT 000H
    MOV  A, E
_smc_prb_pit_ch1_h:
	OUT 000H

    ; === ЭТАП 2: ПРОШИВКА HAL-ВЕКТОРОВ В СЛОТ DE ===
    MOV  H, D
	MOV  L, E
    PUSH H
    LXI  D, O_TTY_HW_PUT_CHAR
	DAD  D
	LXI D, hw_i8251_put_char
	MOV M, E
	INX H
	MOV M, D
    POP  H
	PUSH H
    LXI  D, O_TTY_HW_GET_CHAR
	DAD  D
	LXI D, hw_i8251_get_char
	MOV M, E
	INX H
	MOV M, D
    POP  H
	PUSH H
    LXI  D, O_TTY_HW_POLL_STAT
	DAD  D
	LXI D, hw_i8251_poll_status
	MOV M, E
	INX H
	MOV M, D
    POP  H
	PUSH H
    LXI  D, O_TTY_HW_CHIP_TYPE
	DAD  D
	MVI M, CHIP_TYPE_I8251
    POP  H

    POP  H
	POP  D
	POP  B        ; Восстановили оригинальный контекст
    ANA  A                          ; CY = 0 (Полный успех детекта)
    RET

_i8251_probe_fail_exit:
    POP  H
	POP  D
	POP  B        ; Восстановили РОН супервизора
    STC                             ; CY = 1 (Авария: ВВ51 или ВИ53 не прошел тест!)
    RET

; =============================================================================
; ПРОЦЕДУРА: hw_i8251_poll_status (ИСПРАВЛЕННАЯ ДИНАМИЧЕСКАЯ ВЕРСИЯ)
; Вход:  DE = Физический адрес 160-байтового TTY-слота (TTY0..TTY3)
; Задача: Считать аппаратный статус чипа ОДИН РАЗ по SMC-порту и вернуть маску HAL
; Выход: А  = Байт системного статуса HAL (биты TTY_HAL_TXRDY, TTY_HAL_RXRDY)
;        Регистры BC, DE, HL полностью сохранены согласно контракту HAL.
; =============================================================================
hw_i8251_poll_status:
    PUSH B
    PUSH H                          ; Сохранили РОН супервизора

    ; --- Извлекаем базовый порт из переданной структуры DE ---
    MOV  H, D
    MOV  L, E                       ; HL = База TTY-слота
    LXI  B, O_TTY_HW_BASE_PORT
    DAD  B                          ; HL -> O_TTY_HW_BASE_PORT (+155)
    MOV  A, M                       ; A = BASE_PORT данных чипа
    INR  A                          ; A = BASE_PORT + 1 (Порт команд/статуса ВВ51А)
    
    ; --- SMC-ПАТЧИНГ: Прошиваем вычисленный порт строго в операнд (+1) ---
    STA  _smc_stat_51_patch + 1
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

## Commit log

2026-06-29 Fix error's & optimization
    [eMMU.kicad_sch]
2026-07-19 Update
    add kernel panic function;
    add RTC&NVRAM;
    fix bug's & error's.
    [tty_core.asm]
2026-07-23 Update
    Change PCB from 64 to 128 byte for
    100% POSIX compability.
    Fix 8259 address error.
    Add marcos IRET for kernel return opcode.

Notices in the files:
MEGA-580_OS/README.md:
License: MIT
